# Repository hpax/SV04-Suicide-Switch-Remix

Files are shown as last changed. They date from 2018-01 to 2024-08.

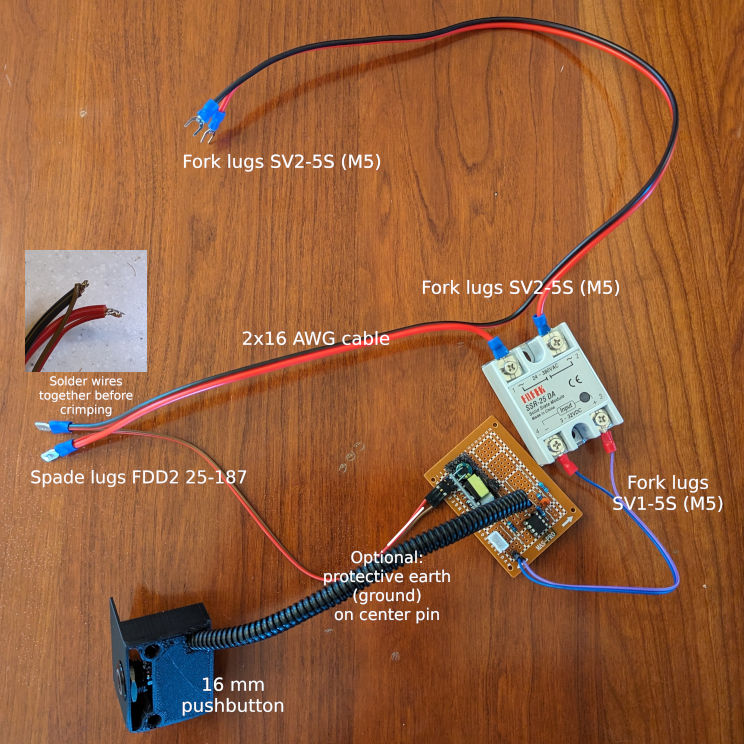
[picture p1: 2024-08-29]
hw/wiring.jpg

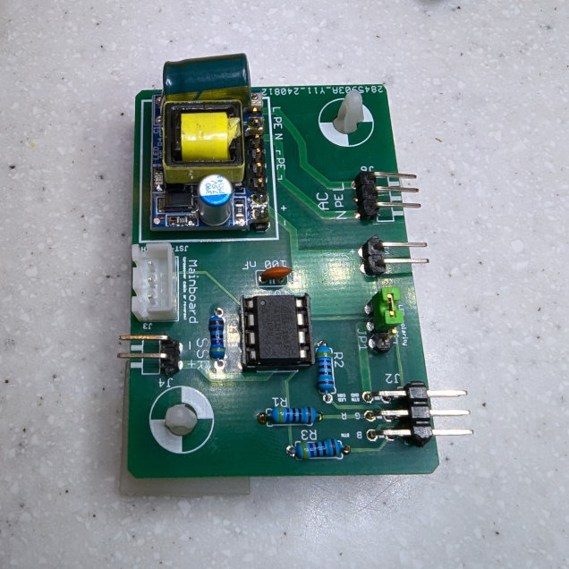
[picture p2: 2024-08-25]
hw/assembled.jpg

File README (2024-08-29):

Soft-off power button for the Sovol SV04 3D printer, using an RGB LED
pushbutton, a miniature 5V standby power supply module, and an
ATtiny85 microcontroller.

(I used ATtiny85 because I had them on hand. ATtiny25/45 would work
just as well, but seem to be hard to get in DIP8 packages anymore. The
-V versions would work as well, but are typically more expensive.)

The bracket in this tree holds a 16 mm (hole diameter) pushbutton. See
hw/powerctl-sch.pdf for the expected pinout of the connection to the
control board.

Either common anode or common cathode LED buttons can be used: both the
board jumper/connection JP1 and the firmware EEPROM needs to
configured accordingly.

The prebuilt firmware is configured for common anode; for common
cathode, change byte 0 of the EEPROM data file (onoff.eeprom.bin) to
0x28 rather than 0x3b (clear bits 4, 1, 0) or change LED_COMMON_ANODE
in sw/leds.h and recompile.

See the comment near the top of sw/eeprom.h for all the configuration
options can be set using the EEPROM without recompiling.

It is not technically necessary to use an RGB pushbutton. A
one- or two-color pushbutton can be used just as well; the
microcontroller can even dim or pulse the LED(s) if desirable. The
prebuilt firmware uses the LEDs as follows:

	RED	- AC power available, power off
	GREEN	- Button is pressed
	BLUE	- Power on

As the circuit is very simple, I originally used a stripboard rather
than waiting for a custom PCB. However, this turned out to be
mechanically unstable and cracked after a bit. Instead, I ended up
designing a PCB; the design files and a .zip file with CAM files
compatible with JLCPCB (https://jlcpcb.com/) are included. Uploading
that .zip file to their website and they make 5 circuit boards for a
few USD including the cheapest shipping.

The firmware uses avr-gcc and avr-libc; it does not require the
Arduino build environment or boot loader. Note that since all 6 I/O
pins are in use, the RESET DISABLE fuse needs to be programmed, and a
standalone (high voltage) programmer needs to be used. I recommend
socketing the MCU.

If you get a precrimped JST cable you apparently want to be careful
with the pinout (straight or crossover.) I found myself having bought
the latter. The pin that should be connected to the microcontroller
matches the one facing to the REAR of the SV04 mainboard connector J2
(yellow color on the adjacent wires.) Either kind of cable can be
used; simply rotate the connector on the stripboard appropriately.

The silkscreen on the PCB reflects the crossover cable configuration,
since that is what I was using.

Instead of using an SSR, you can opt to upgrade your power supply to
one which supports remote power control. However, most power supplies
are *active low* unlike the SSR, so in that case you will need to
change the polarity of the output in the firmware (or set bit 2 in
byte 0 of the EEPROM); you should also remove resistor R4.

To enable the M81 poweroff G-code command, you need a patch to the
mainboard firmware to define the following options in the Marlin
pinout configuration:

#define SUICIDE_PIN		PE4	/* Connector J2 */
#define SUICIDE_PIN_STATE	LOW

You can use bjoern70's patched firmware:

  https://github.com/Bjoern70/SV04-IDEX-3D-Printer-Mainboard-Source-code

or I have a patch to johncarlson21's Marlin 2.1.x tree:

  https://github.com/hpax/SV04-Marlin-2.1.x.git

Both of those requires the appropriate display firmware update.

Alternatively, adding the above two lines into the file
Marlin/src/pins/stm32f1/pins_CREALITY_V4.h of the stock Sovol firmware
should work too (in which case a display firmware change should not
be necessary as long as you are running the latest one already):

  https://github.com/Sovol3d/SV04-IDEX-3D-Printer-Mainboard-Source-code.git

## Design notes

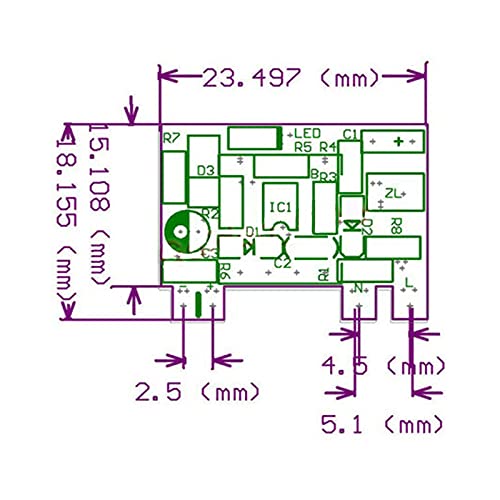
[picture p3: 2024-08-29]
hw/wx-dc12003-dimension.jpg

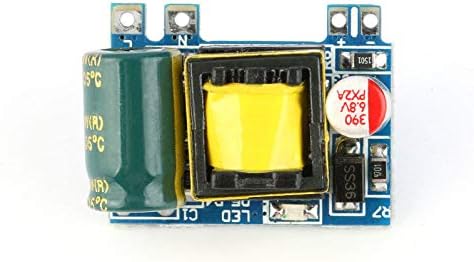
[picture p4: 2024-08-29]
hw/wx-dc12003.jpg

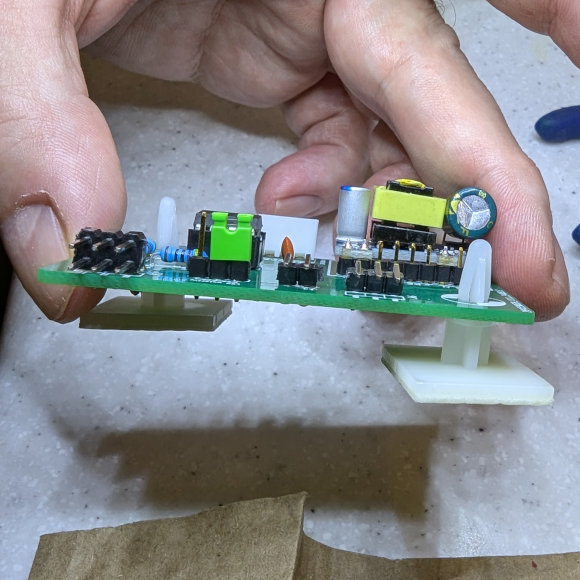
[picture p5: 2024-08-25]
hw/standoffs.jpg

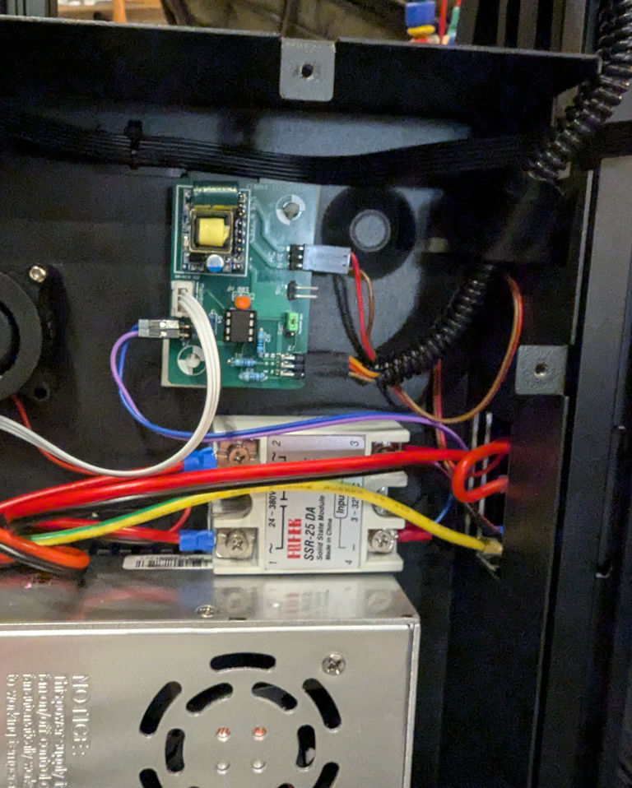
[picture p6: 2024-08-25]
hw/mounting.jpg

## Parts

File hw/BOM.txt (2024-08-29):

Bill of Materials:

J1   - 1x2 angled or straight 2.54" pin header
       ! optional, for testing, SSR bypass, or +5V standby power output
J2   - 2x3 angled 2.54" pin header
J3   - JST-B3B-XH header (1x3 JST XH)
       ! see README for how to orient this header!!
J4   - 1x2 angled 2.54" pin header
J5   - 1x9 straight 2.54" pin header
J6   - 1x3 angled 2.54" pin header
JP1  - 1x3 straight 2.54" pin header
       ! optional: can also be permanently configured with a piece of wire
R1-3 - 3x 470 ohm 0.25 W resistor
R4   - 4.7 kohm 0.25 W resistor
C1   - 100 nF (0.1 µF) ceramic or polymer capacitor
U1   - ATtiny85-PU (25, 25V, 45, 45V or 85V also usable)
     - 8-pin DIP socket
     - 16 mm RGB pushbutton
       ! other sizes possible with a different bracket design
       ! common anode or common cathode both OK (see README)
     - 5V miniature power supply WX-DC12003 or similar (100 mA or more)
       ! check the voltage: WX-DC12003 is available in multiple
       versions
     - SSR-25-DA solid state relay (recommend min 15 A, 5 V activation voltage)
     - mounting screws for SSR
     - 2x spade lug FDD2 25-187
     - 2x fork lug SV2-5S (M5)
     - 2x fork lug SV1-5S (M5)
     - wire with 1x2 DuPont connector, for SSR
     - wire with 1x3 DuPont connector, for standby AC power
     - wire with 2x3 DuPont connector, for pushbutton
     - 2x16 AWG cable
     - short stretch of black 0.5" cable hose or shrink wrap
       ! optional, for aestetics
     - 1x3 JST-XH jumper cable
     - 2x PCB standoff (PC standard 4 mm holes)
       ! can be metal screw in (typically a U.S. 6-32 tapped hole) or adhesive
         nylon, which does not require making additional screw holes
	 in the case.)
     - 2x 20 mm M3 machine screws (for mounting bracket)
     - 2x M3 T-nuts (for mounting bracket)

See wiring.jpg for how to build the wiring harness.

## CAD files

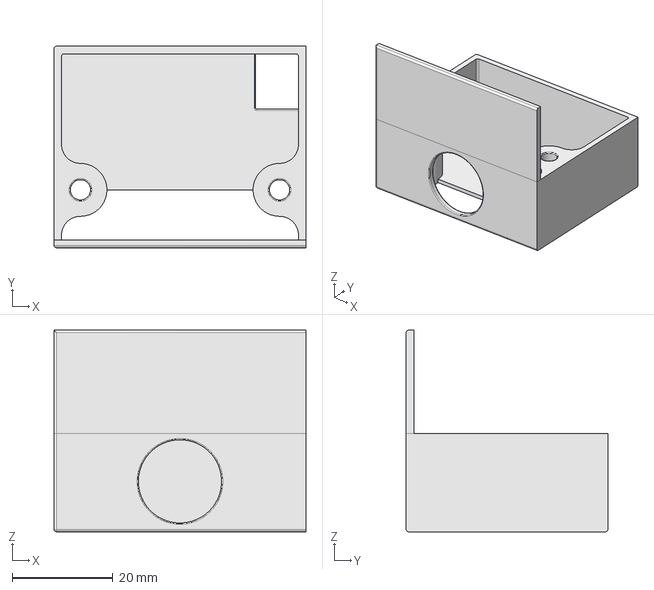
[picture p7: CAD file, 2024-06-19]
bracket/bracket.FCStd
50.0 x 40.0 x 40.0 mm

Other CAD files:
bracket/bracket.stl

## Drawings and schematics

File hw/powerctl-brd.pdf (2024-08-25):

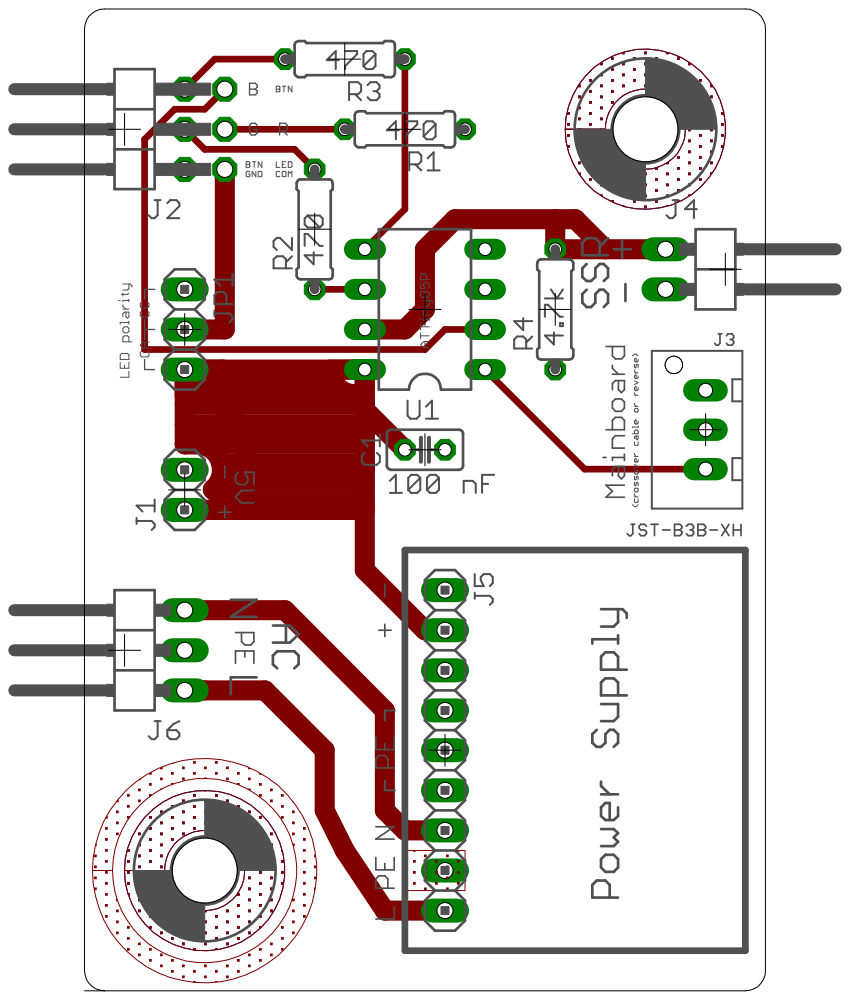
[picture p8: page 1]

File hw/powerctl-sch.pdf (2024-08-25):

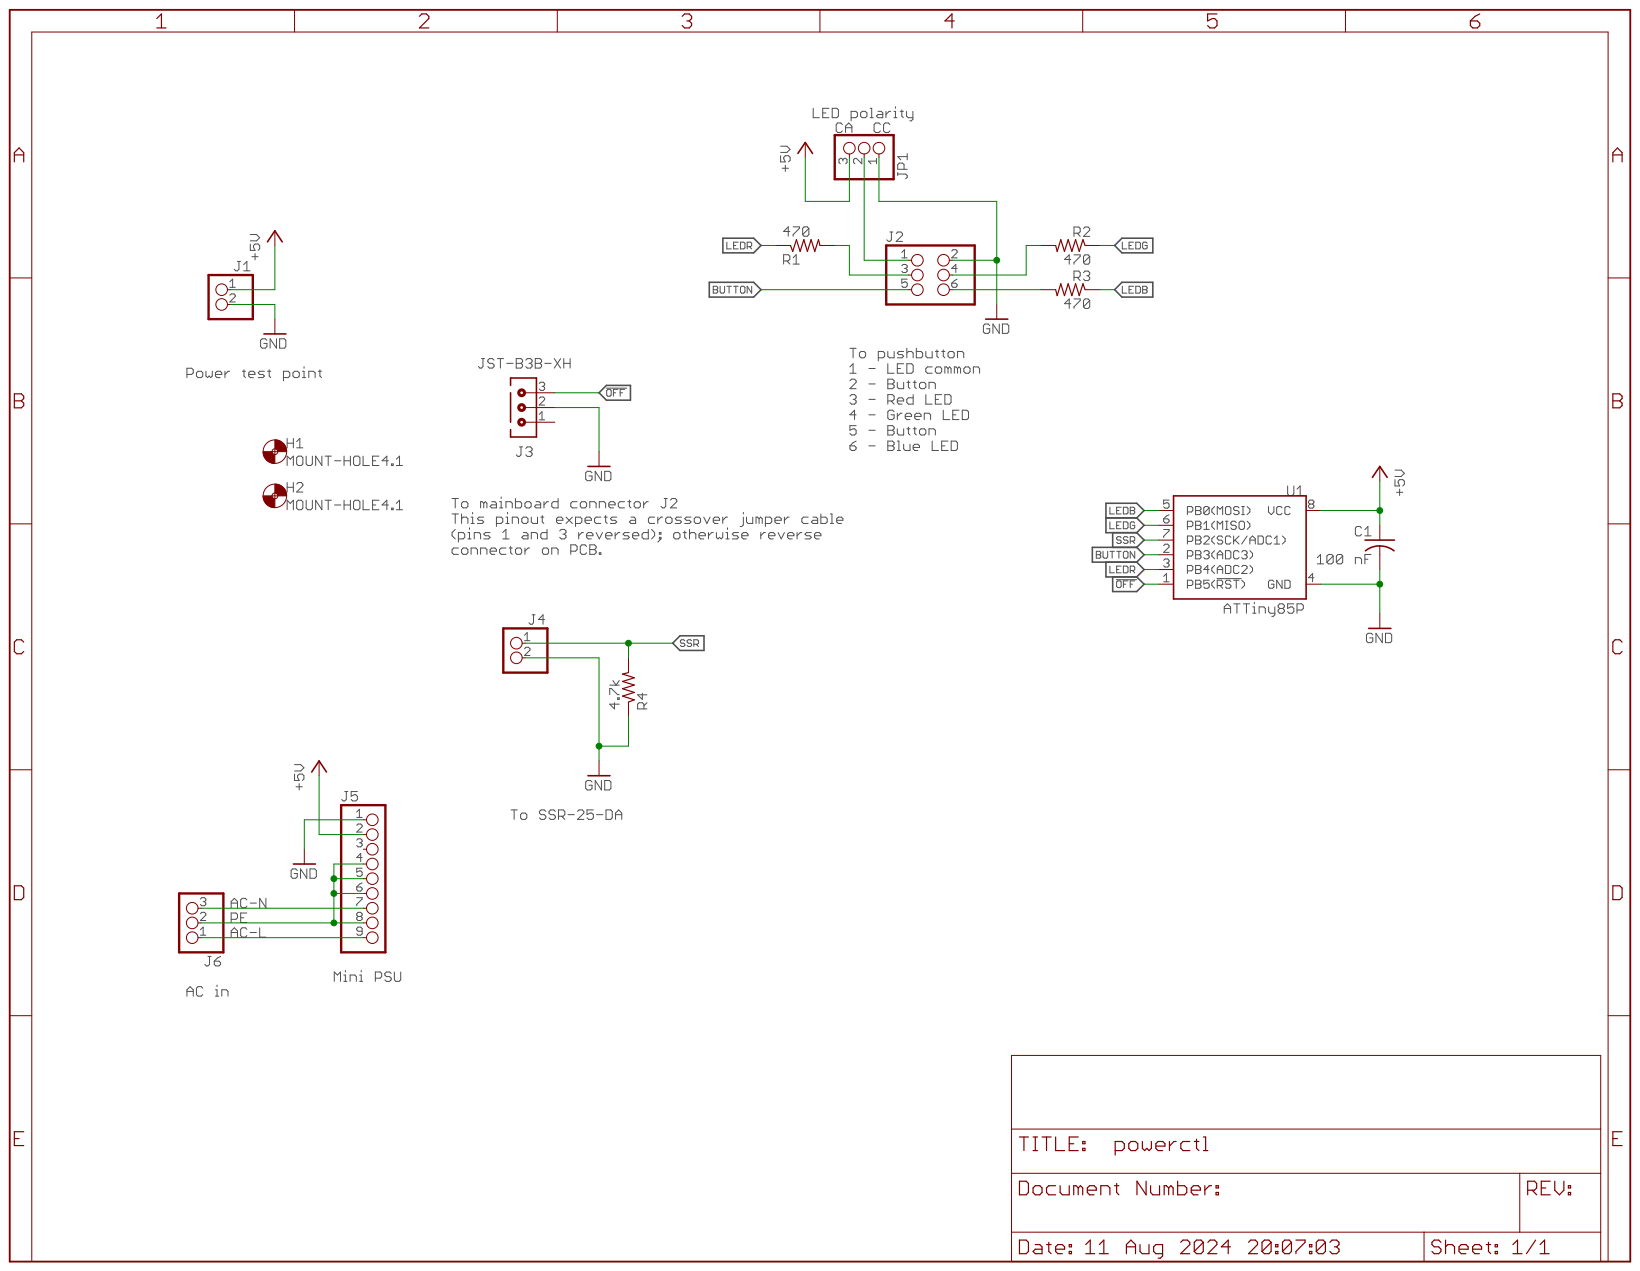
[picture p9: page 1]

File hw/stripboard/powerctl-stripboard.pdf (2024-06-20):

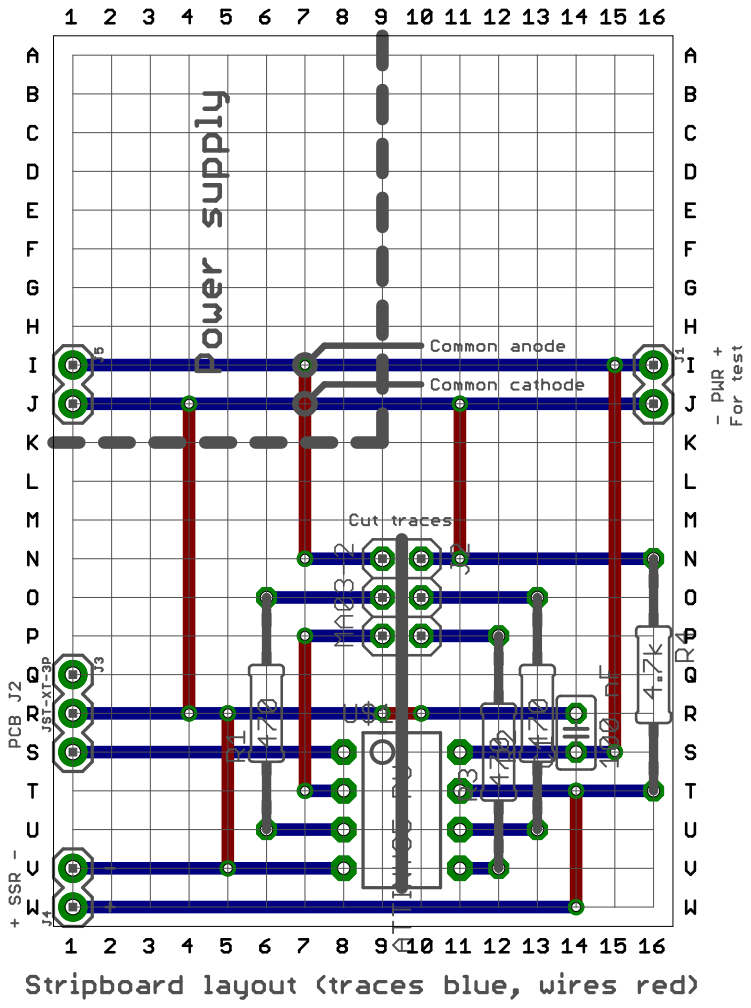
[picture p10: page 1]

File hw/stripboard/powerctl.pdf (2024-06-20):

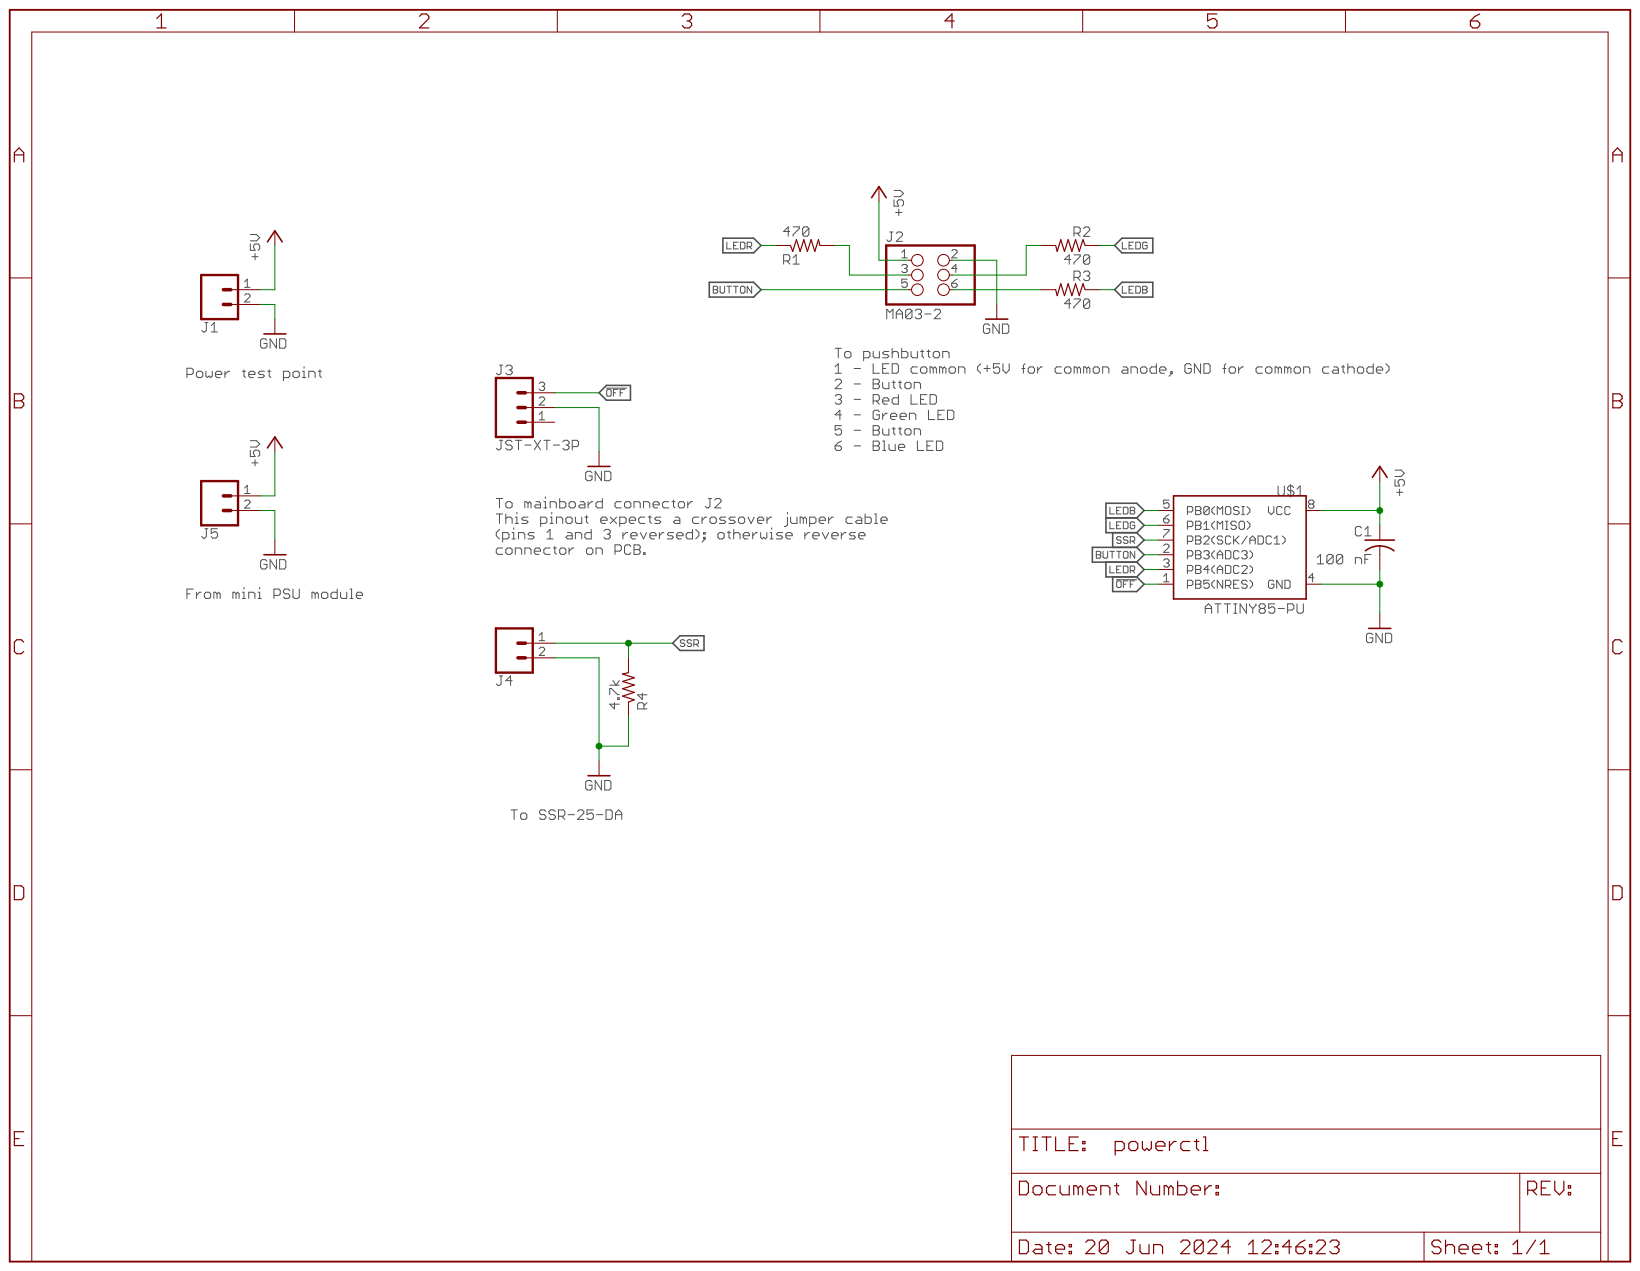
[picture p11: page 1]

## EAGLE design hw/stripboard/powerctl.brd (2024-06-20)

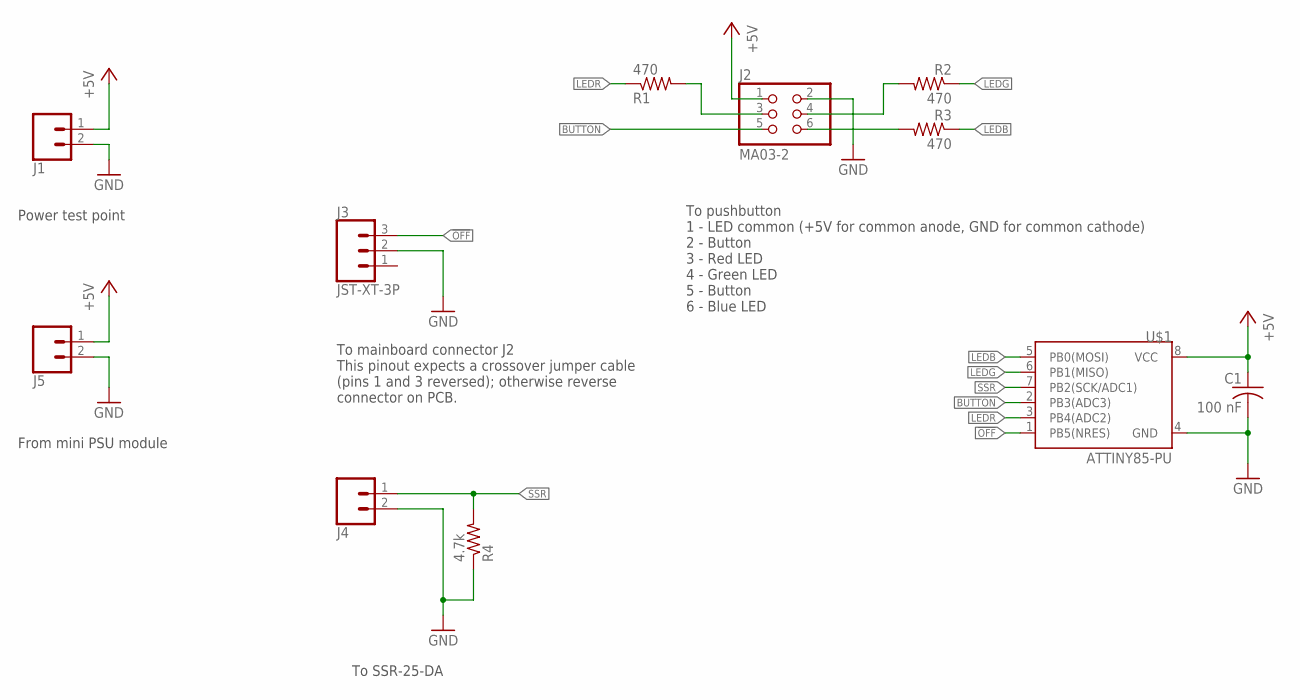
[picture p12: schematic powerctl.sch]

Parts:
C1: 100 nF; C025-025X050
J1, J4, J5: CONN_02; 1X02
J2: MA03-2; 2X03
J3: JST-XT-3P; 1X03
R1, R2, R3: 470; 0207/15
R4: 4.7k; 0207/15
U$1: ATTINY85-PU; DIP08

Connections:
!OFF: J3.3, U$1.1 (PB5(NRES))
+5V: C1.1, J1.1, J2.1, J5.1, U$1.8 (VCC)
BUTTON: J2.5, U$1.2 (PB3(ADC3))
GND: C1.2, J1.2, J2.2, J3.2, J4.2, J5.2, R4.1, U$1.4 (GND)
LEDB: R3.1, U$1.5 (PB0(MOSI))
LEDG: R2.1, U$1.6 (PB1(MISO))
LEDR: R1.1, U$1.3 (PB4(ADC2))
unnamed: J2.6, R3.2
unnamed: J2.3, R1.2
unnamed: J2.4, R2.2
SSR: J4.1, R4.2, U$1.7 (PB2(SCK/ADC1))

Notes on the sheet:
From mini PSU module
Power test point
To pushbutton 1 - LED common (+5V for common anode, GND for common cathode) 2 - Button 3 - Red LED 4 - Green LED 5 - Button 6 - Blue LED
To mainboard connector J2 This pinout expects a crossover jumper cable (pins 1 and 3 reversed); otherwise reverse connector on PCB.
To SSR-25-DA

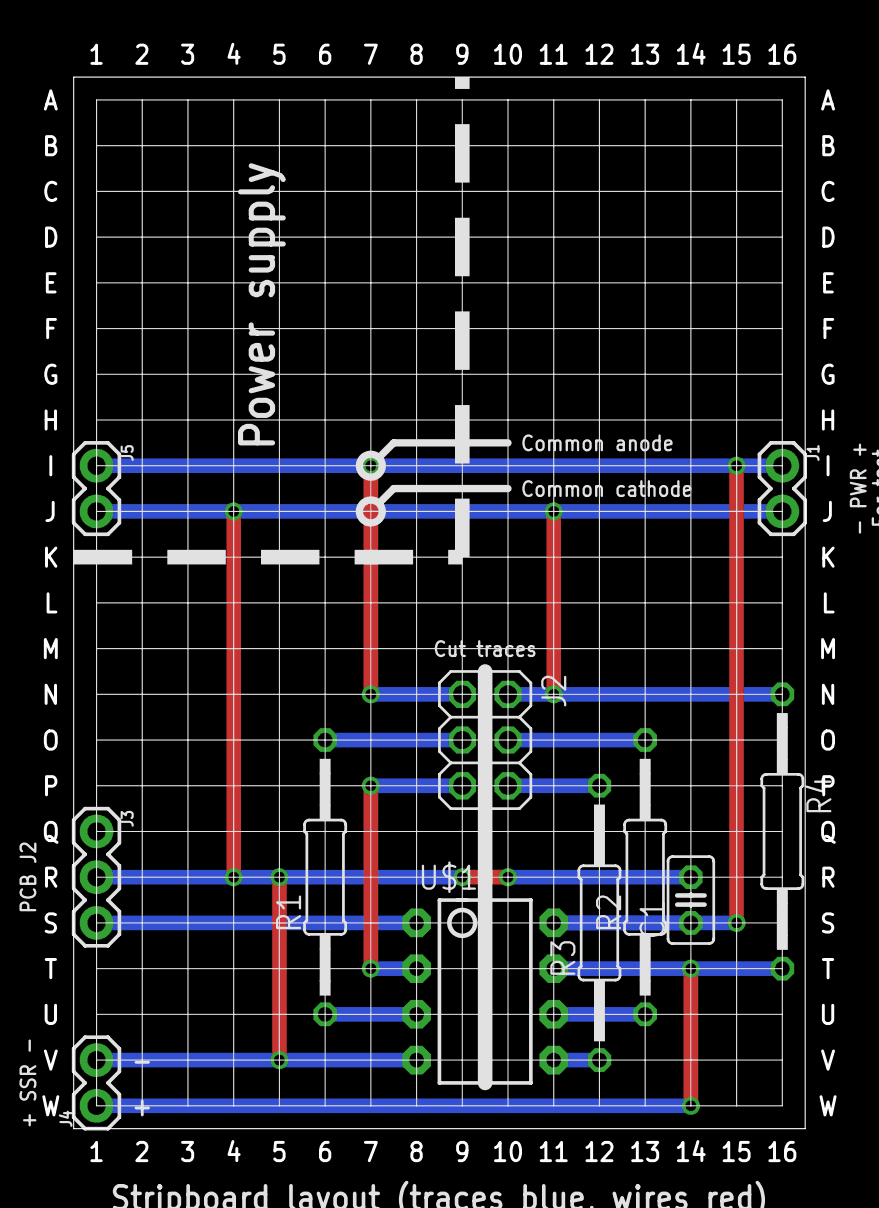
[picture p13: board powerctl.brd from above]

Board: 2 copper layers, 40.6 x 58.4 mm, 11 parts (0 on the bottom side), 11 nets.

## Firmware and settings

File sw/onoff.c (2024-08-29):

#include "util.h"
#include "pins.h"
#include "timer.h"
#include "led.h"
#include "eeprom.h"

/* Fuse settings */
FUSES = {
    /* Clock: internal 1 MHz */
    .low	= LFUSE_DEFAULT,
    /* All pins in use as GPIO, no reset/debugwire/SPI programming */
    .high	= FUSE_RSTDISBL,
    /* Self-programming of flash is not used, so disabled */
    .extended	= EFUSE_DEFAULT
};

/* Default flash speed on power up (units of 260 ms, minus one) */
#define FLASH_SPEED	7

/* Default delays in units of 65.536 ms */
#define MIN_DELAY	2	/* Time before deglitch assumed stable */
#define MIN_OFF_DELAY	32	/* Time before power off is enabled */
#define BUTTON_PRESS	4	/* Time before button is considered pressed */
#define BUTTON_CANCEL	48	/* Time before button press is cancelled */

/*
 * EEPROM variables - used for configuration to avoid needing to
 * recompile the firmware to tweak these variables.
 */
static EEMEM struct eeprom eeprom = {
    .polarity           = PINB_POLARITY,
    .flash_speed	= FLASH_SPEED,
    .min_delay          = MIN_DELAY,
    .min_off_delay      = MIN_OFF_DELAY,
    .button_press       = BUTTON_PRESS,
    .button_cancel      = BUTTON_CANCEL
};
struct eeprom ee;

static void load_eeprom(void)
{
    eeprom_read_block((void *)&ee, &eeprom, sizeof ee);
    EECR = 0;			/* For future programming operations */
}

static inline __attribute__((const))
uint8_t inactive(bool active_low, uint8_t mask) {
    return active_low ? mask : 0;
}

static uint8_t portb_power_off;	/* PORTB output value with SSR off */

static void init(void)
{
    /* Initializing... */
    cli();

    /* Get EEPROM copy in RAM */
    load_eeprom();

    /*
     * Default configuration; see pins.h
     *
     * Inputs:
     * OFF#    - PB5 - pin 1 - power off from mainboard
     * BUTTON# - PB3 - pin 2 - pushbutton
     * Outputs:
     * OC1B    - PB4 - pin 3 - red LED	  (active low)
     * OC0A    - PB0 - pin 5 - blue LED   (active low)
     * OC0B    - PB1 - pin 6 - green LED  (active low)
     * SSR     - PB2 - pin 7 - SSR enable (active high)
     *
     * Initially drive everything to its inactive state; enable
     * pullups on inputs (set to 1 regardless of sense)
     */
    portb_power_off = ee.polarity | PINMASK_BUTTON | PINMASK_OFF;
    PORTB = portb_power_off;
    MCUCR = 0x00;		/* Enable input pullups, sleep mode = idle */
    DDRB  = PINMASK_LEDS|PINMASK_SSR;

    /* Timer interrupt and status */
    TIMSK  = (1 << 1) | (1 << 2);	/* Enable timer 0&1 overflow IRQs */
    TIFR   = 0xff;			/* Clear all pending interrupts */

    /* COMxx bit 0 sets the polarity of PWM output */
    uint8_t oc0a_pol = (ee.polarity & 0x01) << (6-0); /* PB0 */
    uint8_t oc0b_pol = (ee.polarity & 0x02) << (4-1); /* PB1 */
    uint8_t oc1b_pol = (ee.polarity & 0x10) << (4-4); /* PB4 */

    /*
     * Timer 1 programming
     *
     * HARDWARE ERRATUM: COM1Ax must be = COM1Bx or OC1B PWM output
     * does not work.  Fortunately the PWM from timer 0 seems to take
     * priority on pin PB1.
     */
    /* OC1B enabled, inverted PWM mode;  */
    uint8_t gtccr_config = (1 << 6) | (2 << 5) | oc1b_pol;
    /* Bits to be held until after configuration */
#define GTCCR_SYNC	((1 << 7) | (1 << 0))

    GTCCR = gtccr_config | GTCCR_SYNC;
    PLLCSR = 0;
    TCCR1 = (1 << 7) | (0 << 6) | (2 << 4) | (1 << 0) | oc1b_pol;
    OCR1C = 255;		     /* Run from 0 to 255 */

    /*
     * Timer 0 programming
     *
     * OC0A/OC0B are set up in inverting phase correct PWM mode.
     * This gives a dynamic range from (0-255):255.
     */
    TCCR0A = (2 << 6) | (2 << 4) | (1 << 0) | oc0a_pol | oc0b_pol;
    TCCR0B = (0 << 3) | (1 << 0);

    /* Disable all LEDs */
    OCR0A = OCR0B = OCR1B = 0;

    /* Enable PWM counters */
    GTCCR = gtccr_config;

    /* Disable pin interrupts */
    GIMSK = 0;
    PCMSK = 0;

    /* Global enable interrupts */
    sei();
}

static inline void set_power_on(bool power)
{
    uint8_t portb = portb_power_off;
    if (power)
	portb ^= PINMASK_SSR;
    PORTB = portb;
}

static void set_button_led(bool button)
{
    set_led(LED_G, button ? LED_ON : LED_OFF);
}

static void set_power_led(bool power)
{
    set_led(LED_R, power ? LED_OFF : LED_ON);
    set_led(LED_B, power ? LED_ON : LED_OFF);
}
static void set_power_led_init(bool power)
{
    set_led(LED_R, power ? LED_OFF : LED_FLASH);
    set_led(LED_B, power ? LED_ON  : LED_OFF);
}


/*
 * Nonvolatile last power status; used to detect power failures.
 * After a power failure when the power was ON, flash the button
 * for attention.
 */


enum button_mode {
    BUTTON_RELEASED,
    BUTTON_DELAYING,
    BUTTON_ACTIVE,
    BUTTON_CANCELLED
};

static void __attribute__((noreturn)) loop(void)
{
    /*
     * Poll both the pushbutton and the power off input with
     * debounce. The power off input is ignored if the power is
     * already off.
     */
    bool     button_state     = false;
    uint8_t  button_mode      = BUTTON_RELEASED;
    bool     power            = false;
    bool     old_off_state    = false;
    bool     delay_armed      = false;
    bool     off_armed        = false;
    uint16_t button_when      = 0;
    uint16_t power_when       = 0;

    set_all_led(LED_OFF);

    while (true) {
	uint16_t now;

	/* Nothing to do until next interrupt */
	asm volatile("sleep");

	cli();
	now          = _timer.tick.w[0];
	button_state = _timer.button.state;
	sei();

	/* Let the debounce stabilize */
	if (!delay_armed) {
	    if ((now >> 8) < ee.min_delay)
		continue;
	    delay_armed = true;
	    set_power_led_init(power);
	    set_button_led(button_state);
	    button_mode = button_state
		? BUTTON_CANCELLED : BUTTON_RELEASED;
	}

	if (!button_state) {
	    /* Button released */
	    if (button_mode != BUTTON_RELEASED) {
		if (button_mode == BUTTON_ACTIVE) {
		    power = !power;
		    set_power_on(power);
		    set_power_led(power);
		}
		set_button_led(false);
		button_mode = BUTTON_RELEASED;
	    }
	} else {
	    uint8_t hold_time = (now - button_when) >> 8;
	    /* Button pressed */
	    switch (button_mode) {
	    case BUTTON_RELEASED:
		button_when = now;
		set_button_led(true);
		button_mode = BUTTON_DELAYING;
		break;
	    case BUTTON_DELAYING:
		if (hold_time >= ee.button_press) {
		    set_power_led(!power);
		    button_mode = BUTTON_ACTIVE;
		}
		break;
	    case BUTTON_ACTIVE:
		if (hold_time >= ee.button_cancel) {
		    set_power_led(power);
		    set_button_led(false);
		    button_mode = BUTTON_CANCELLED;
		}
		break;
	    default:
		break;
	    }
	}

	if (!power) {
	    /*
	     * A signal from the mainboard can never be valid when
	     * the mainboard itself is turned off. The arming timer
	     * runs from when power is turned on via the SSR.
	     */
	    off_armed   = false;
	    power_when  = now;
	    continue;
	}

	uint8_t off_state = _timer.off.state;
	if (!off_armed) {
	    uint16_t hold_time = now - power_when;
	    if ((hold_time >> 8) < ee.min_off_delay) {
		old_off_state = off_state;
		continue;
	    }
	    off_armed = true;
	}

	if (off_state && !old_off_state) {
	    set_power_on(power = false);
	    set_power_led(false);
	    if (button_mode != BUTTON_RELEASED) {
		button_mode = BUTTON_CANCELLED;
		set_button_led(false);
	    }
	}
	old_off_state = off_state;
    }
}

int main(void)
{
    init();
    loop();
}

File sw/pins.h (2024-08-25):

#ifndef PINS_H
#define PINS_H

/* Pinmasks - these are PBx port bit numbers, not physical pins! */
#define HIGH 0
#define LOW  1

/* Mapping between package pins and PBx port numbers */
#define PIN_1			5
#define PIN_2			3
#define PIN_3			4
#define PIN_5			0
#define PIN_6			1
#define PIN_7			2

#define PIN_OFF			PIN_1
#define PIN_OFF_SENSE		LOW
#define PIN_BUTTON		PIN_2
#define PIN_BUTTON_SENSE	LOW
#define PIN_SSR			PIN_7
#define PIN_SSR_SENSE		HIGH

#define PIN_LED_R		PIN_3
#define PIN_LED_B		PIN_5
#define PIN_LED_G		PIN_6

/* LED polarity */
#define LED_COMMON_ANODE	1

/* Deglitch hysteresis in timer ticks (256 µs) */
#define BUTTON_DEGLITCH		256
#define OFF_DEGLITCH		256

/* PBx port numbers, not physical pins! */
#define PINMASK_OFF	(1U << PIN_OFF)
#define PINMASK_BUTTON	(1U << PIN_BUTTON)
#define PINMASK_SSR	(1U << PIN_SSR)
#define PINMASK_LED_R	(1U << PIN_LED_R)
#define PINMASK_LED_B	(1U << PIN_LED_B)
#define PINMASK_LED_G	(1U << PIN_LED_G)

#define PINMASK_LEDS	(PINMASK_LED_R|PINMASK_LED_G|PINMASK_LED_B)

#define PINB_POLARITY					     \
    ((PIN_BUTTON_SENSE << PIN_BUTTON) |			     \
     (PIN_OFF_SENSE << PIN_OFF) |			     \
     (PIN_SSR_SENSE << PIN_SSR) |			     \
     (LED_COMMON_ANODE ? PINMASK_LEDS : 0))

#endif

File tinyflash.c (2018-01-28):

#include "tinyflash.h"

static void delay(void)
{
	_delay_ms(2);
}

int main(void)
{
	/* Initializing... */
	cli();

	/*
	 * Outputs are:
	 * OC0A - PB0 - pin 5
	 * OC0B - PB1 - pin 6
	 * OC1B - PB4 - pin 3
	 */
	MCUCR = 0x20;		/* Enable input pullups, sleep mode = idle */
	DDRB  = 0x13;		/* PB0,1,4 as outputs */
	PORTB = 0x3f;		/* Pullups on all inputs */

	/* Timer interrupt and status */
	TIMSK  = 0;
	TIFR   = 0;

	/*
	 * Timer 0 programming
	 *
	 * OC0A/OC0B are set up in inverting phase correct PWM mode.
	 * This gives a dynamic range from (0-255):255.
	 */
	TCCR0A = (3 << 6) | (3 << 4) | (1 << 0);
	TCCR0B = (0 << 3) | (1 << 0);

	OCR0A  = 255;		/* Off */
	OCR0B  = 255;		/* Off */

	/*
	 * Timer 1 programming
	 *
	 * HARDWARE ERRATUM: COM1Ax must be = COM1Bx or OC1B PWM output
	 * does not work.  Fortunately the PWM from timer 0 seems to take
	 * priority on pin PB1.
	 */
	PLLCSR = 0;
	TCCR1 = (1 << 7) | (0 << 6) | (3 << 4) | (1 << 0);
	GTCCR = (1 << 6) | (3 << 4); /* OC1B enabled, inverted PWM mode */
	OCR1C = 255;		     /* Run from 0 to 255 */
	OCR1B = 255;		     /* Off */

	/*
	 * ADC input programming
	 */
	DIDR0  = 0x08;		/* Analog input on ADC3/PB3/pin 2 */
	ADMUX  = 0x03;		/* Single ended input on ADC3 vs Vcc */
	ADCSRA = 0;		/* Disabled for now */

	/* We are now in a "safe" place to enable interrupts */
	sei();

	/*
	 * OCR0A = R
	 * OCR0B = G
	 * OCR1B = B
	 */
	/* Pulse R */
	for (uint8_t i = 1; i; i++) {
		OCR0A = (uint8_t)~i;
		delay();
	}
	for (uint8_t i = 254; i != 255; i--) {
		OCR0A = (uint8_t)~i;
		delay();
	}
	/* Pulse G */
	for (uint8_t i = 1; i; i++) {
		OCR0B = (uint8_t)~i;
		delay();
	}
	for (uint8_t i = 254; i != 255; i--) {
		OCR0B = (uint8_t)~i;
		delay();
	}
	/* Pulse B */
	for (uint8_t i = 1; i; i++) {
		OCR1B = (uint8_t)~i;
		delay();
	}
	for (uint8_t i = 254; i != 255; i--) {
		OCR1B = (uint8_t)~i;
		delay();
	}

	/*
	 * Enable ADC and ADC interrupt
	 */
	ADCSRB = 0x00;		/* Free running mode */
	ADCSRA = 0xec;		/* Enable, auto trigger, IRQ,
				   ck/16 = 62.5 kHz */
	for (;;)
		sleep_cpu();	/* Actual work is done in interrupt handler */
}

/* ADC conversion complete interrupt routine */
ISR(ADC_vect)
{
	uint16_t adc;
	uint8_t r, g, b;

	adc = ADCL;
	adc += (uint16_t)ADCH << 8;

	/* Guard band to make sure we go to black */
	const uint16_t guard = 64;
	adc = (adc < guard) ? 0 : adc-guard;

	r = adc >> 2;
	g = (adc < 341) ? 0 : ((adc-341)*3) >> 3;
	b = (adc < 682) ? 0 : ((adc-682)*3) >> 2;

	OCR0A = (uint8_t)~r;
	OCR0B = (uint8_t)~g;
	OCR1B = (uint8_t)~b;
}

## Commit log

2018-01-27 Sample Makefile
2018-01-28 Use PWM output to control brightness
2018-01-28 tinyflash: use ADC to receive input via potentiometer
2018-01-28 Move work to ADC interrupt handler, let the CPU sleep
    Put the CPU into idle sleep when we are not doing anything, let the
    PWM and ADC units do the work themselves.
2018-05-05 Add hardware files
    [nightlight.brd, nightlight.sch]
2018-05-05 Additional hardware files: compute LED positions
2024-06-15 3D printer on/off system
2024-06-16 onoff.c: fix LED configuration and pin assignments; add LED test
    Fix the LED configuration and the pin assignments.
    If the button is pressed during power on, cycle through colors 8 times
    through the extended rainbow as an LED test before assuming normal
    operation.
    [onoff.c]
2024-06-16 eagle: add schematic (.sch and .pdf)
    No board file since a veroboard was used.
    [nightlight.brd, nightlight.sch, powerctl.sch]
2024-06-16 Rename eagle -> hw
    More appropriate naming of the directory with hardware info.
    [powerctl.sch]
2024-06-19 Add fuses.conf to zipfile; add firmware snapshot
2024-06-19 bracket: add 3D model for bracket
    [bracket.FCStd, bracket.stl]
2024-06-19 hw: update hardware, including warning about JST jumper cable
    Update the hardware schematic to indicate the pinout for the button
    connector, and note the oddness with the apparent commonness(???) of
    JST jumper cable crossover cables.
    [powerctl.sch]
2024-06-19 Add README for the bracket
2024-06-19 Specify 16 mm pushbutton
2024-06-20 Update schematic and add stripboard layout
    [powerctl.brd, powerctl.sch]
2024-06-20 Add images of wiring and case mounting
2024-06-20 Add images for the bracket; move README to the top.
2024-06-20 README: document default LED configuration
2024-06-20 README: add documentation for using a controllable power supply
    Most controllable power supplies are active low, whereas the SSR is
    active high.
2024-06-25 sw: move LED test fade table to progmem
    No reason to put that in RAM...
2024-08-25 User friendliness improvements; PWM for LEDs
    - Pulse red LED after power loss
    - Minimum time for button press recognition
    - Very long button press to cancel
2024-08-25 hw: add PCB hardware definition and CAM files
    [powerctl.brd, powerctl.sch]
2024-08-25 Update mounting images with PCB images
2024-08-25 Correctly use EEPROM variables; update README
    Use the EEPROM configurables in all relevant places. Update the README
    to inform about PCB and settable EEPROM configuration values.
    [onoff.c]
2024-08-29 sw: better eeprom documentation, fix off signal timer, move sleep
    - Document the EEPROM contents in detail in sw/eeprom.h
    - The OFF signal timer should run from the moment power is applied
    to the SSR, not from when AC power is first applied,
    and should be reset whenever the power is disabled.
    - Move the sleep instruction to the top of the loop, so that a
    continue; statement doesn't bypass it.
    [onoff.c]
2024-08-29 README: add more details
    Add more details about the EEPROM, the LEDs, and the JST connector.
2024-08-29 hw: add bill of materials
2024-08-29 BOM: add SSR-25-DA
2024-08-29 BOM: add C1
    C1 was missing from the BOM
2024-08-29 BOM: add mounting screws and T-nuts for bracket
2024-08-29 wiring.jpg: note optional ground on center AC pin
2024-08-29 BOM: add mounting screws for SSR, more explicit requirements

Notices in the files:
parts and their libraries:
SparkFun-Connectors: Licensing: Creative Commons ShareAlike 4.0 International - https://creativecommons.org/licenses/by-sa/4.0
